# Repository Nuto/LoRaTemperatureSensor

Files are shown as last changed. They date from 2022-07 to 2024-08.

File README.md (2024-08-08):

# LTS - LoRa Temperature Sensor
A Temperature Sensor connected via LoRa with a Master Module with a WLAN connection.

The aim of this project is to record the temperatures of the individual units in a small apartment complex in order to obtain an overall picture of the heating and cooling performance. The sensor data of the slave modules are then sent via LoRa to the master module. This then forwards the data via WLAN to a cloud service. This means that each slave module does not have to have its own WLAN configuration.

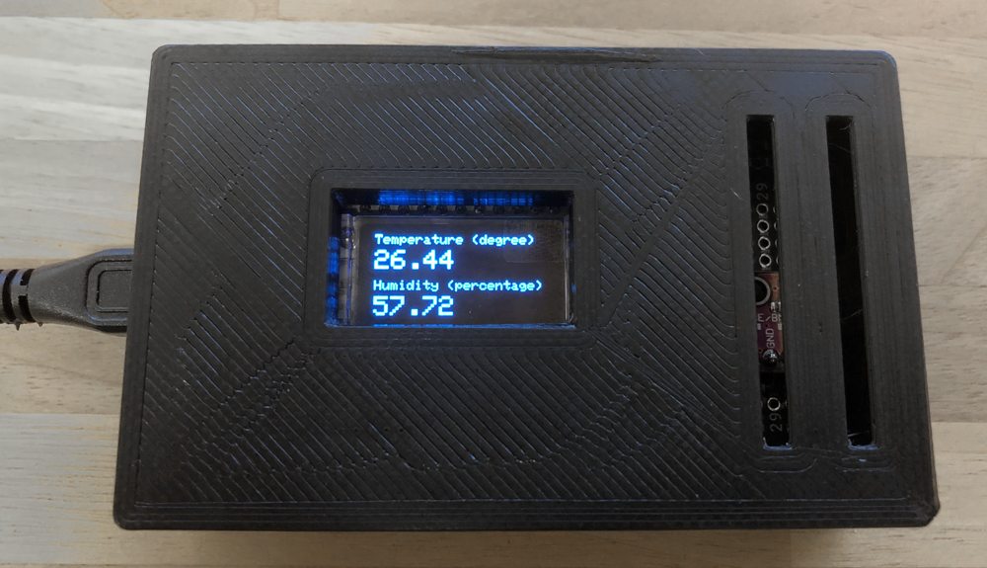
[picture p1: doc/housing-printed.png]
Housing printed


```mermaid
flowchart TD
    A[Temperature and Humidity Sensor 'sensor-v3'] -->|LoRa communication| B(LoRa WLAN Gateway 'gateway-v3')
    B -->|WLAN communication| C(Internet Router)
    C --> D(iotplotter)
```

## LoRa

### RSSI
The Received Signal Strength Indication (RSSI) is the received signal power in milliwatts and is measured in dBm.
This value can be used as a measurement of how well a receiver can "hear" a signal from a sender.
The closer to 0 the better the signal is, RSSI `minimum is -120dBm`.

- `-30dBm` signal is strong
- `-120dBm` signal is weak

### Tools

- https://loratools.nl/#/airtime
- https://dramco.be/tools/lora-calculator/

## Findings

### Housing optimizations

The first housing variant (V1) still had few openings due to the additional optimization, the sensor now reacts faster to changes. The current housing variant is (V2)

### Temperature rise due the BME280 (Humidity & Pressure Sensor)

In the beginning, the temperature always increased the same when I put my sensor into operation. After a little research I then found out that the standard configuration makes 1000 queries per second and thus the temperature sensor heats up this I have now solved so that I manually trigger the sensor to query the temperature value and this now happens only 1 time per second.

### Temperature rise due to the esp32 (CPU)

When measuring with a thermal imaging camera, it is now clearly visible that the `ESP32` heats up the housing disadvantageously in continuous operation and influences the temperature measurement with a very high probability. The next development steps therefore go in the direction of deep sleep to improve this behavior. After my first tests in deep sleep I could see a temperature difference of `1.5°` which is the `deep sleep` code optimization.

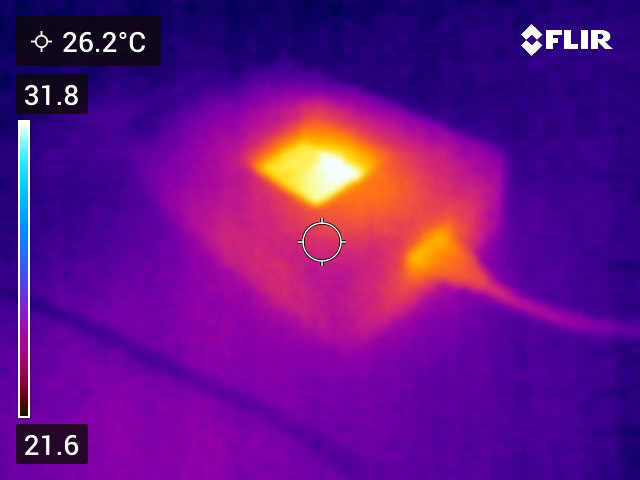
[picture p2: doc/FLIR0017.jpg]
thermal camera


### Sensor configuration

Adjusting the sensor name each time in the code before compiling was very inconvenient and error-prone. Since the ESP32 has no EEPROM I have now stored the values in the flash via the `Preferences` library.

### LoRa to LoRa communication (Without LoRaWan)

[lora-serialization](https://github.com/thesolarnomad/lora-serialization), [CayenneLPP](https://www.thethingsnetwork.org/docs/devices/arduino/api/cayennelpp/), [protobuf](https://github.com/protocolbuffers/protobuf) The protocols are too complicated to implement a simple device-to-device communication.

### Sensor broken

The humidity sensor stopped working after a good 2 years. It now only delivers 100% values. It was only used indoors, but the humidity reached 100%. If you search for it on the Internet, other people seem to have the same problem.

## Used Hardware

- [1x Heltec - WIFI LoRa 32 - V2.1 (SX1276)](https://amzn.to/3NMaJKi)
- [1x AZDelivery GY-BME280 Temperature Sensor](https://amzn.to/3Aph1wp)
- [1x Prototype Board](https://amzn.to/3OXw8Bc)

## Used Software Packages

- [espressif - arduino-esp32](https://raw.githubusercontent.com/espressif/arduino-esp32/gh-pages/package_esp32_index.json)
  (httpclient is more up to date than like heltec)
- [sandeepmistry - arduino-LoRa](https://github.com/sandeepmistry/arduino-LoRa)
- [adafruit - Adafruit_BME280](https://github.com/adafruit/Adafruit_BME280_Library)
- [adafruit - Adafruit_SSD1306](https://github.com/adafruit/Adafruit_SSD1306)

## Housing

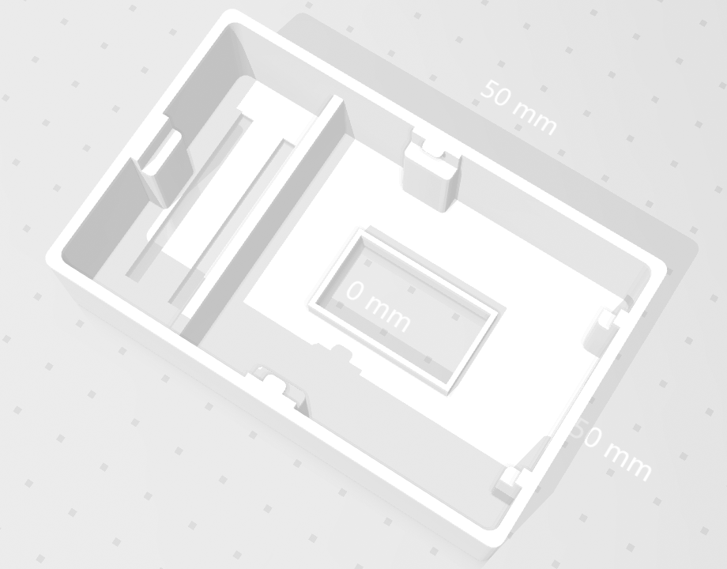
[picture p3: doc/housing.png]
Housing
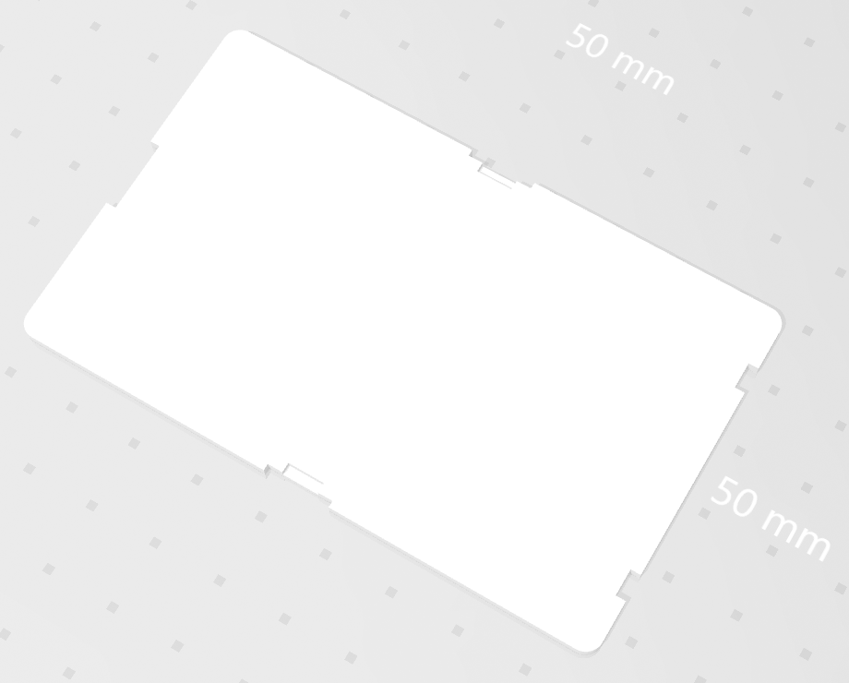
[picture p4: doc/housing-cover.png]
Housing Cover
 

## Sensor data targets

| Tool | Description |
| --- | --- |
| https://iotplotter.com | Simple tool to visualize fast data but there is no real configuration for the endpoints |
| https://datagekko.com | Currently not yet available is in a closed beta |
| https://iotguru.live | Not tested |
| https://thingspeak.com | Not tested |
| https://thingsboard.io | Not tested |

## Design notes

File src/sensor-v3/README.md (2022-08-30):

# Sensor V3

## Advantages

- Deep sleep (Improved heat generation in the housing)
- Optimized for battery operation
- No LoRaWAN required, communication via LoRa to the Gateway-Module
- Optimized size of LoRa Data Package

## Available commands

- `config.muid=2` Set the module identifier (1-254)
- `config.tc=-0.2` Set a temperature compensation

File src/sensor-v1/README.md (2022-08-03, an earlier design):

# Sensor V1

## Advantages

- Permanently active display (temperature and humidty)
- Temperature average of the last 20 values
- No LoRaWAN required, communication via LoRa to the Gateway-Module

## Disadvantages

- No deep sleep (heat generation in the housing)

## Available commands

- `config.muid=LSM2` Set the module name
- `config.tc=-0.2` Set a temperature compensation
- `reset` Restart the module

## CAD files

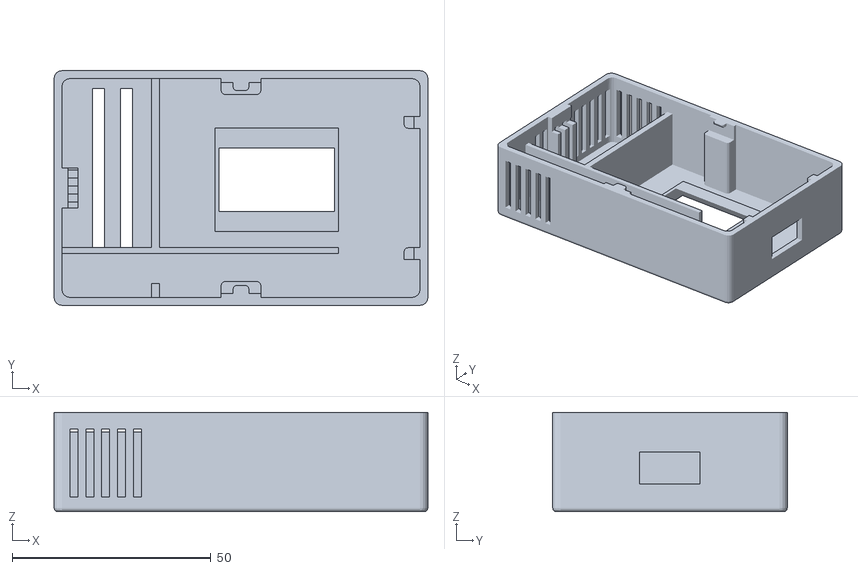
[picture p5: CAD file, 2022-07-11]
res/housing-v2.stl
94.0 x 59.0 x 25.0

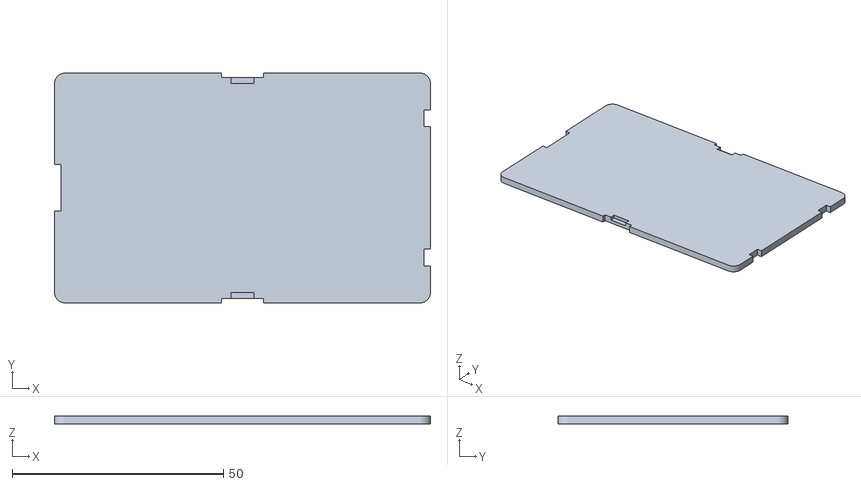
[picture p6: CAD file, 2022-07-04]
res/housing-cover.stl
89.0 x 54.4 x 2.00

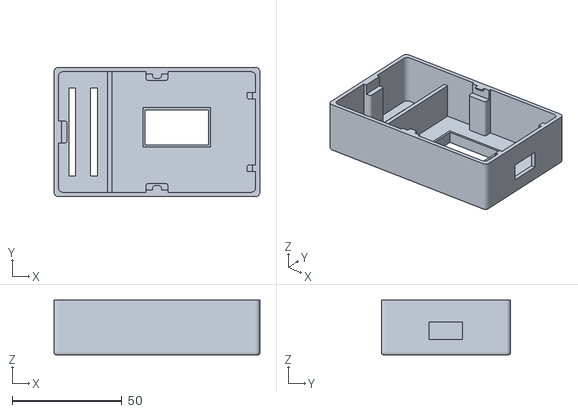
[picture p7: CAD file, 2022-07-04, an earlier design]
res/housing-v1.stl
94.0 x 59.0 x 25.0

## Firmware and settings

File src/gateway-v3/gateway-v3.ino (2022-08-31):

//Secrets
#include "secrets.h"

//Bitmaps
#include "bitmaps.h"

//Libraries for LORA
#include <SPI.h>
#include "LoRa.h"

//Libraries for WLAN
#include <WiFi.h>

//Display
#include "display.h"

//Prepare WLAN (please enter your sensitive data in the tab -> arduino_secrets.h)
const char* ssid = SECRET_WLAN_SSID;
const char* password = SECRET_WLAN_PASS;

//Libraries for WebRequests
#include <HTTPClient.h>

//Prepare LORA
#define BAND    868E6

unsigned long previousMillis = 0UL;
unsigned long interval = 1000UL; //1s

#define BUTTON_PIN 0
int buttonPressed = 0;

volatile unsigned int receiveCounter;
volatile bool loraDataAvailable;
volatile int receivedPacketSize;

unsigned int failureCounter;

void onReceive(int packetSize) {
  receivedPacketSize = packetSize;
  receiveCounter++;
  loraDataAvailable = true;
}

void initializeLoRa() {
  displayClear();
  displaySmallText(0, 0, "Initialize");
  displayLargeText(0, 20, "LoRa");
  displayDraw();

  Serial.println(F("Initialize LoRa"));
  SPI.begin(SCK, MISO, MOSI, SS);
  //LoRa.setPins(SS,RST_LoRa,DIO0);
  LoRa.setPins(18, 14, 26);
  if (!LoRa.begin(BAND))
  {
    Serial.println(F("LoRa initialization failed!"));
    while (1);
  }

  LoRa.setTxPower(20, PA_OUTPUT_PA_BOOST_PIN); //Supported values are 2 to 20 for PA_OUTPUT_PA_BOOST_PIN

  LoRa.setPreambleLength(8); //ranges from 6-65535
  LoRa.setSyncWord(0x91); //ranges from 0-0xFF, default 0x34, see API docs

  //setLoraProfileLongRange();
  setLoraProfileUltraLongRange();

  LoRa.onReceive(onReceive);
  LoRa.receive(); //activate receive mode

  delay(500);
}

void setLoraProfileLongRange() {
  //Lora Send Configuration examples
  //https://github.com/dragino/Arduino-Profile-Examples/blob/master/libraries/Dragino/examples/LoRa/LoRa_Simple_Client_Arduino/LoRa_Simple_Client_Arduino.ino
  //Documentation Source: https://josefmtd.com/2018/08/14/spreading-factor-bandwidth-coding-rate-and-bit-rate-in-lora-english/
  LoRa.setSignalBandwidth(31.25E3);
  //LoRa modulation also adds a forward error correction (FEC) in every data transmission.
  //This implementation is done by encoding 4-bit data with redundancies into 5-bit, 6-bit, 7-bit, or even 8-bit.
  //Using this redundancy will allow the LoRa signal to endure short interferences.
  //The Coding Rate (CR) value need to be adjusted according to conditions of the channel used for data transmission.
  //If there are too many interference in the channel, then it’s recommended to increase the value of CR.
  //However, the rise in CR value will also increase the duration for the transmission
  LoRa.setCodingRate4(8); //ranges from 5-8, default 5
  //The value of Spreading Factor (SF) determines how many chips used to represent a symbol.
  //The higher the SF value is, the more chips used to represent a symbol, which means there will be more processing gain from the receiver side.
  //This will allow receiver to accept data signals with negative SNR value
  LoRa.setSpreadingFactor(9); //ranges from 7-12, default 7
}

void setLoraProfileUltraLongRange() {
  //Lora Send Configuration examples
  //https://github.com/dragino/Arduino-Profile-Examples/blob/master/libraries/Dragino/examples/LoRa/LoRa_Simple_Client_Arduino/LoRa_Simple_Client_Arduino.ino
  //Documentation Source: https://josefmtd.com/2018/08/14/spreading-factor-bandwidth-coding-rate-and-bit-rate-in-lora-english/
  LoRa.setSignalBandwidth(125E3);
  //LoRa modulation also adds a forward error correction (FEC) in every data transmission.
  //This implementation is done by encoding 4-bit data with redundancies into 5-bit, 6-bit, 7-bit, or even 8-bit.
  //Using this redundancy will allow the LoRa signal to endure short interferences.
  //The Coding Rate (CR) value need to be adjusted according to conditions of the channel used for data transmission.
  //If there are too many interference in the channel, then it’s recommended to increase the value of CR.
  //However, the rise in CR value will also increase the duration for the transmission
  LoRa.setCodingRate4(8); //ranges from 5-8, default 5
  //The value of Spreading Factor (SF) determines how many chips used to represent a symbol.
  //The higher the SF value is, the more chips used to represent a symbol, which means there will be more processing gain from the receiver side.
  //This will allow receiver to accept data signals with negative SNR value
  LoRa.setSpreadingFactor(12); //ranges from 7-12, default 7
}

void initializeWLAN() {
  Serial.print(F("Initialize WLAN"));

  displayClear();
  displaySmallText(0, 0, "Initialize");
  displayLargeText(0, 20, "WLAN");
  displayDraw();

  WiFi.disconnect(true);
  delay(1000);

  WiFi.mode(WIFI_STA);
  WiFi.setAutoConnect(true);
  WiFi.setAutoReconnect(true);
  WiFi.setHostname("LDTS-Gateway");
  WiFi.begin(ssid, password);

  byte retryCount = 0;
  byte maxRetries = 15;
  Serial.print(F(", try connect["));
  while (WiFi.status() != WL_CONNECTED && retryCount < maxRetries) {
    retryCount++;
    delay(500);
    Serial.print(".");
  }
  Serial.print(F("]"));

  Serial.println();

  if (WiFi.status() == WL_CONNECTED) {
    displaySmallText(0, 44, "Connected");
    displayDraw();
    delay(1000);

    return;
  } else {
    displaySmallText(0, 44, "Cannot connect");
    displayDraw();

    Serial.println(F("WLAN initialization failed!"));
    while (1);
  }
}

void showLogo() {
  displayClear();
  displayLogo();
  displayDraw();
  delay(2000);
}

void sendWebRequest(String sensorName, float temperature, byte humidity) {
  //String httpRequestData = "0," + graphName + "," + String(temperature);
  String httpRequestData = "{\"data\":{\"" + sensorName + "t\":[{\"value\":" + String(temperature) + "}],\"" + sensorName + "h\":[{\"value\":" + String(humidity) + "}]}}";

  HTTPClient httpClient;
  httpClient.setConnectTimeout(2000);
  
  //httpClient.begin("https://webhook.site/5e077421-31f1-4ab2-a6b3-a52579a1f652");
  if (!httpClient.begin("http://iotplotter.com/api/v2/feed/831079989972422411")) {
    failureCounter++;
    httpClient.end();
    return;
  }
  
  httpClient.addHeader("api-key", "");
  httpClient.addHeader("Content-Type", "application/x-www-form-urlencoded");
  httpClient.setTimeout(5000); //5 seconds
  
  int httpCode = httpClient.POST(httpRequestData);
  analyzeSystemHttpCodes(httpCode);
  
  httpClient.end();

  Serial.println("iotplotter.com response code:" + String(httpCode) + ", Send Data(" + httpRequestData + ")");
  if (httpCode != 200) {
    failureCounter++;
  }
}

void analyzeSystemHttpCodes(int httpCode) {
  if (httpCode == HTTPC_ERROR_CONNECTION_REFUSED) {
    Serial.println(F("HTTPC_ERROR_CONNECTION_REFUSED"));
  } else if (httpCode == HTTPC_ERROR_SEND_HEADER_FAILED) {
    Serial.println(F("HTTPC_ERROR_SEND_HEADER_FAILED"));
  } else if (httpCode == HTTPC_ERROR_SEND_PAYLOAD_FAILED) {
    Serial.println(F("HTTPC_ERROR_SEND_PAYLOAD_FAILED"));
  } else if (httpCode == HTTPC_ERROR_NOT_CONNECTED) {
    Serial.println(F("HTTPC_ERROR_NOT_CONNECTED"));
  } else if (httpCode == HTTPC_ERROR_CONNECTION_LOST) {
    Serial.println(F("HTTPC_ERROR_CONNECTION_LOST"));
  } else if (httpCode == HTTPC_ERROR_NO_STREAM) {
    Serial.println(F("HTTPC_ERROR_NO_STREAM"));
  } else if (httpCode == HTTPC_ERROR_NO_HTTP_SERVER) {
    Serial.println(F("HTTPC_ERROR_NO_HTTP_SERVER"));
  } else if (httpCode == HTTPC_ERROR_TOO_LESS_RAM) {
    Serial.println(F("HTTPC_ERROR_TOO_LESS_RAM"));
  } else if (httpCode == HTTPC_ERROR_ENCODING) {
    Serial.println(F("HTTPC_ERROR_ENCODING"));
  } else if (httpCode == HTTPC_ERROR_STREAM_WRITE) {
    Serial.println(F("HTTPC_ERROR_STREAM_WRITE"));
  } else if (httpCode == HTTPC_ERROR_READ_TIMEOUT) {
    Serial.println(F("HTTPC_ERROR_READ_TIMEOUT"));
  }
}

uint8_t crc8maxim(uint8_t *addr, uint8_t len) {
  uint8_t crc = 0;
  for (uint8_t i = 0; i < len; i++) {
    uint8_t inbyte = addr[i];
    for (uint8_t j = 0; j < 8; j++) {
      uint8_t mix = (crc ^ inbyte) & 0x01;
      crc >>= 1;
      if (mix) {
        crc ^= 0x8C;
      }
      inbyte >>= 1;
    }
  }
  return crc;
}

void setup() {
  //Prepare Serial connection
  Serial.begin(115200);
  Serial.println("Initialize system");

  pinMode(BUTTON_PIN, INPUT_PULLUP);

  resetOledDisplay();
  initializeOledDisplay();
  showLogo();
  initializeLoRa();
  initializeWLAN();

  Serial.println("System is ready");
}

void loop() {

  buttonPressed = digitalRead(BUTTON_PIN);
  if (buttonPressed == 0) { //If pressed
    displayOn();
  } else {
    displayOff();
  }

  unsigned long currentMillis = millis();
  if (currentMillis - previousMillis > interval) {
    displayClear();
    displaySmallText(0, 0, "Received packages");
    displayLargeText(0, 14, String(receiveCounter));
    displaySmallText(0, 44, "Failures: " + String(failureCounter));
    displayDraw();

    previousMillis = currentMillis;
  }

  if (loraDataAvailable) {
    loraDataAvailable = false;

    uint8_t message[5];
    if (receivedPacketSize) // Only read if there is some data to read..
    {
      //Print packet infos
      Serial.print("Receive package");
      Serial.print("' with RSSI ");
      Serial.println(LoRa.packetRssi());
      
      int num = LoRa.readBytes((uint8_t *)&message, receivedPacketSize);
      if (num != 5) {
        failureCounter++;
        Serial.println("invalid package length");
        return;
      }

      uint8_t checksumCalculated = crc8maxim((uint8_t *)&message, 4);
      if (message[4] == checksumCalculated) {

        String sensorName = "LSM" + String(message[0]);

        int temperature1 = (message[1]/16*10) + (message[1]%16);
        int temperature2 = (message[2]/16*10) + (message[2]%16);
        float temperature = temperature1 + (float(temperature2)/100);
        byte humidity = message[3];
        
        Serial.print("Message from ");
        Serial.println(sensorName);
        Serial.print("Temperature:");
        Serial.println(temperature);
        Serial.print("Humidity:");
        Serial.println(humidity);

        sendWebRequest(sensorName, temperature, humidity);
      } else {
        Serial.println("invalid checksum");
        failureCounter++;
      }
    }
  }
}

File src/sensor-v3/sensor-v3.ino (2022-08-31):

//Bitmaps
#include "bitmaps.h"

//Libraries for LoRa
#include <SPI.h>
#include <LoRa.h>

//Libraries for BME280
#include <Wire.h>
#include <Adafruit_Sensor.h>
#include <Adafruit_BME280.h>

//Display
#include "display.h"

//Configuration
#include "configuration.h"

//Prepare BME280 Sensor
#define SDA 21
#define SCL 22

Adafruit_BME280 bme;
//Prepare a second I2C wire for Sensor
TwoWire I2Cone = TwoWire(1);

//Prepare LoRa
#define BAND    868E6

//Sensor config
#define ROLLING_AVERAGE_DATAPOINT_NUMBER 20

//Deep Sleep
#define uS_TO_S_FACTOR 1000000  /* Conversion factor for micro seconds to seconds */
#define TIME_TO_SLEEP  5        /* Time ESP32 will go to sleep (in seconds) */

esp_sleep_wakeup_cause_t wakeup_reason;

RTC_DATA_ATTR unsigned int bootCount = 0;
RTC_DATA_ATTR unsigned int loopCounter;

float temperature;
float humidity;
float pressure;

RTC_DATA_ATTR float lastSentTemperature;
RTC_DATA_ATTR float lastSentHumidity;

char temperatureRounded[4];

uint8_t moduleUniqueidentifier;
float temperatureCompensation;

uint8_t message[5];

void initializeLoRa(bool displayOutput, int delayDuration) {

  if (displayOutput) {
    displayClear();
    displaySmallText(0, 0, "Initialize");
    displayLargeText(0, 20, "LoRa");
    displayDraw();
  }

  Serial.println(F("Initialize LoRa"));
  SPI.begin(SCK, MISO, MOSI, SS);
  LoRa.setPins(18, 14, 26);

  if (!LoRa.begin(BAND))
  {
    Serial.println(F("LoRa initialization failed!"));
    while (1);
  }

  LoRa.setTxPower(20, PA_OUTPUT_PA_BOOST_PIN); //Supported values are 2 to 20 for PA_OUTPUT_PA_BOOST_PIN

  LoRa.setPreambleLength(8); //ranges from 6-65535
  LoRa.setSyncWord(0x91); //ranges from 0-0xFF, default 0x34, see API docs

  //setLoraProfileLongRange();
  setLoraProfileUltraLongRange();

  //Debugging
  //LoRa.dumpRegisters(Serial);

  delay(delayDuration);
}

void setLoraProfileLongRange() {
  //Lora Send Configuration examples
  //https://github.com/dragino/Arduino-Profile-Examples/blob/master/libraries/Dragino/examples/LoRa/LoRa_Simple_Client_Arduino/LoRa_Simple_Client_Arduino.ino
  //Documentation Source: https://josefmtd.com/2018/08/14/spreading-factor-bandwidth-coding-rate-and-bit-rate-in-lora-english/
  LoRa.setSignalBandwidth(31.25E3);
  //LoRa modulation also adds a forward error correction (FEC) in every data transmission.
  //This implementation is done by encoding 4-bit data with redundancies into 5-bit, 6-bit, 7-bit, or even 8-bit.
  //Using this redundancy will allow the LoRa signal to endure short interferences.
  //The Coding Rate (CR) value need to be adjusted according to conditions of the channel used for data transmission.
  //If there are too many interference in the channel, then it’s recommended to increase the value of CR.
  //However, the rise in CR value will also increase the duration for the transmission
  LoRa.setCodingRate4(8); //ranges from 5-8, default 5
  //The value of Spreading Factor (SF) determines how many chips used to represent a symbol.
  //The higher the SF value is, the more chips used to represent a symbol, which means there will be more processing gain from the receiver side.
  //This will allow receiver to accept data signals with negative SNR value
  LoRa.setSpreadingFactor(9); //ranges from 7-12, default 7
}

void setLoraProfileUltraLongRange() {
  //Lora Send Configuration examples
  //https://github.com/dragino/Arduino-Profile-Examples/blob/master/libraries/Dragino/examples/LoRa/LoRa_Simple_Client_Arduino/LoRa_Simple_Client_Arduino.ino
  //Documentation Source: https://josefmtd.com/2018/08/14/spreading-factor-bandwidth-coding-rate-and-bit-rate-in-lora-english/
  LoRa.setSignalBandwidth(125E3);
  //LoRa modulation also adds a forward error correction (FEC) in every data transmission.
  //This implementation is done by encoding 4-bit data with redundancies into 5-bit, 6-bit, 7-bit, or even 8-bit.
  //Using this redundancy will allow the LoRa signal to endure short interferences.
  //The Coding Rate (CR) value need to be adjusted according to conditions of the channel used for data transmission.
  //If there are too many interference in the channel, then it’s recommended to increase the value of CR.
  //However, the rise in CR value will also increase the duration for the transmission
  LoRa.setCodingRate4(8); //ranges from 5-8, default 5
  //The value of Spreading Factor (SF) determines how many chips used to represent a symbol.
  //The higher the SF value is, the more chips used to represent a symbol, which means there will be more processing gain from the receiver side.
  //This will allow receiver to accept data signals with negative SNR value
  LoRa.setSpreadingFactor(12); //ranges from 7-12, default 7
}

void terminateLoRa() {
  LoRa.end();
  SPI.end();
}

void initializeTemperatureSensor(bool displayOutput, int delayDuration) {

  if (displayOutput) {
    displayClear();
    displaySmallText(0, 0, "Initialize");
    displayLargeText(0, 20, "T&H");
    displayNormalText(56, 28, "Sensor");
    displayDraw();
  }

  //Set Pins for BME280 Sensor
  I2Cone.begin(SDA, SCL, 100000);

  if (!bme.begin(0x76, &I2Cone)) {
    Serial.println(F("Could not find a valid BME280 sensor, check wiring!"));
    while (1);
  }

  //The sensor requires special protection so that it does not falsify the measurement data due to its own heat
  bme.setSampling(Adafruit_BME280::MODE_FORCED,   //Query the sensor data only on command
                  Adafruit_BME280::SAMPLING_X1, //Temperature
                  Adafruit_BME280::SAMPLING_X1, //Pressure
                  Adafruit_BME280::SAMPLING_X1, //Humidity
                  Adafruit_BME280::FILTER_X2);  //Specifies how many samples are required until in the case of an abrupt change in the measured value the data output has followed at least 75% of the change

  bme.takeForcedMeasurement();

  //Set value from config
  float temperatureCompensation = getTemperatureCompensation();
  bme.setTemperatureCompensation(temperatureCompensation);

  Serial.print("TemperatureCompensation: ");
  Serial.println(temperatureCompensation);

  delay(delayDuration);
}

void showLogo() {
  displayClear();
  displayLogo();
  displayDraw();
  delay(1500);
}

void showModuleInfo() {
  displayClear();
  displaySmallText(0, 0, "Module Identifier");
  displayLargeText(0, 20, "LSM" + String(moduleUniqueidentifier));
  displayDraw();
  Serial.println("Module Identifier: LSM" + String(moduleUniqueidentifier));

  delay(2000);
}

void showSystemReady() {
  displayClear();
  displaySmallText(0, 0, "System Status");
  displayLargeText(0, 20, "Ready");
  displaySmallText(0, 50, "disable Display");
  displayDraw();

  delay(2500);
}
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

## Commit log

2022-07-04 add housing
    [housing-cover.stl, housing.stl]
2022-07-11 Optimize bme sensor config
2022-07-11 Optimize housing
    [housing-v1.stl, housing-v2.stl]
2022-07-12 rename master/slave into gateway/sensor
2022-07-17 optimize sensor configuration
2022-07-20 Optimize sensor logic
    [configuration.h]
2022-07-25 small changes on sensor
2022-07-28 small sensor updates
2022-07-29 add temperature profile info
2022-07-30 start development of new sensor module with deep sleep
    [configuration.h]
2022-07-30 Add new sensor version
2022-08-02 Optimize code
    [configuration.h]
2022-08-30 Add Gateway v3, optimize package structure from sensor
2022-08-30 Add Sensor V3
    [configuration.h]
2022-08-30 Optimize gateway failure counter
    [gateway-v3.ino]
2022-08-31 switch to json api logic to send multiple values
